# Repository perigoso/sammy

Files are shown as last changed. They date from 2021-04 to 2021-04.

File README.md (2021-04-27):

# sammy

The little brother of [big-sammy](https://github.com/openinput-fw/big-sammy)

[](https://github.com/openinput-fw)

Open source wired mouse hardware.

## Specifications
- 8 kHz sampling rate support
- Zero latency switch debounce
- Onboard configuration memory
- 2 main mouse buttons (satellite* configuration for both)
- 2 side buttons (symmetric to allow easy left/right handedness)
- encoder + wheel button (satellite* configuration)
- RGB Led

`*meaning, a separate board from the core with the controller and sensor`

## Hardware



- ATSAMS70 MCU (ATSAM3UxC)
- Optical sensor [PMW3330, PMW3360, PMW3389, Truemove3]
- onboard conectors:
    - JST PH (2mm pitch) for USB
    - JST SH (1mm pitch) for stellite boards
- M2 mounting hardware

|USB pinout||
|-----|-----|
|1|VCC|
|2|DM|
|3|DP|
|4|GND|
|5|Shield|

## Firmware

sammy is meant to run on [openinput](https://github.com/openinput-fw/openinput).

## License

This hardware is licensed under the [CERN-OHL-P v2](LICENSE) license.

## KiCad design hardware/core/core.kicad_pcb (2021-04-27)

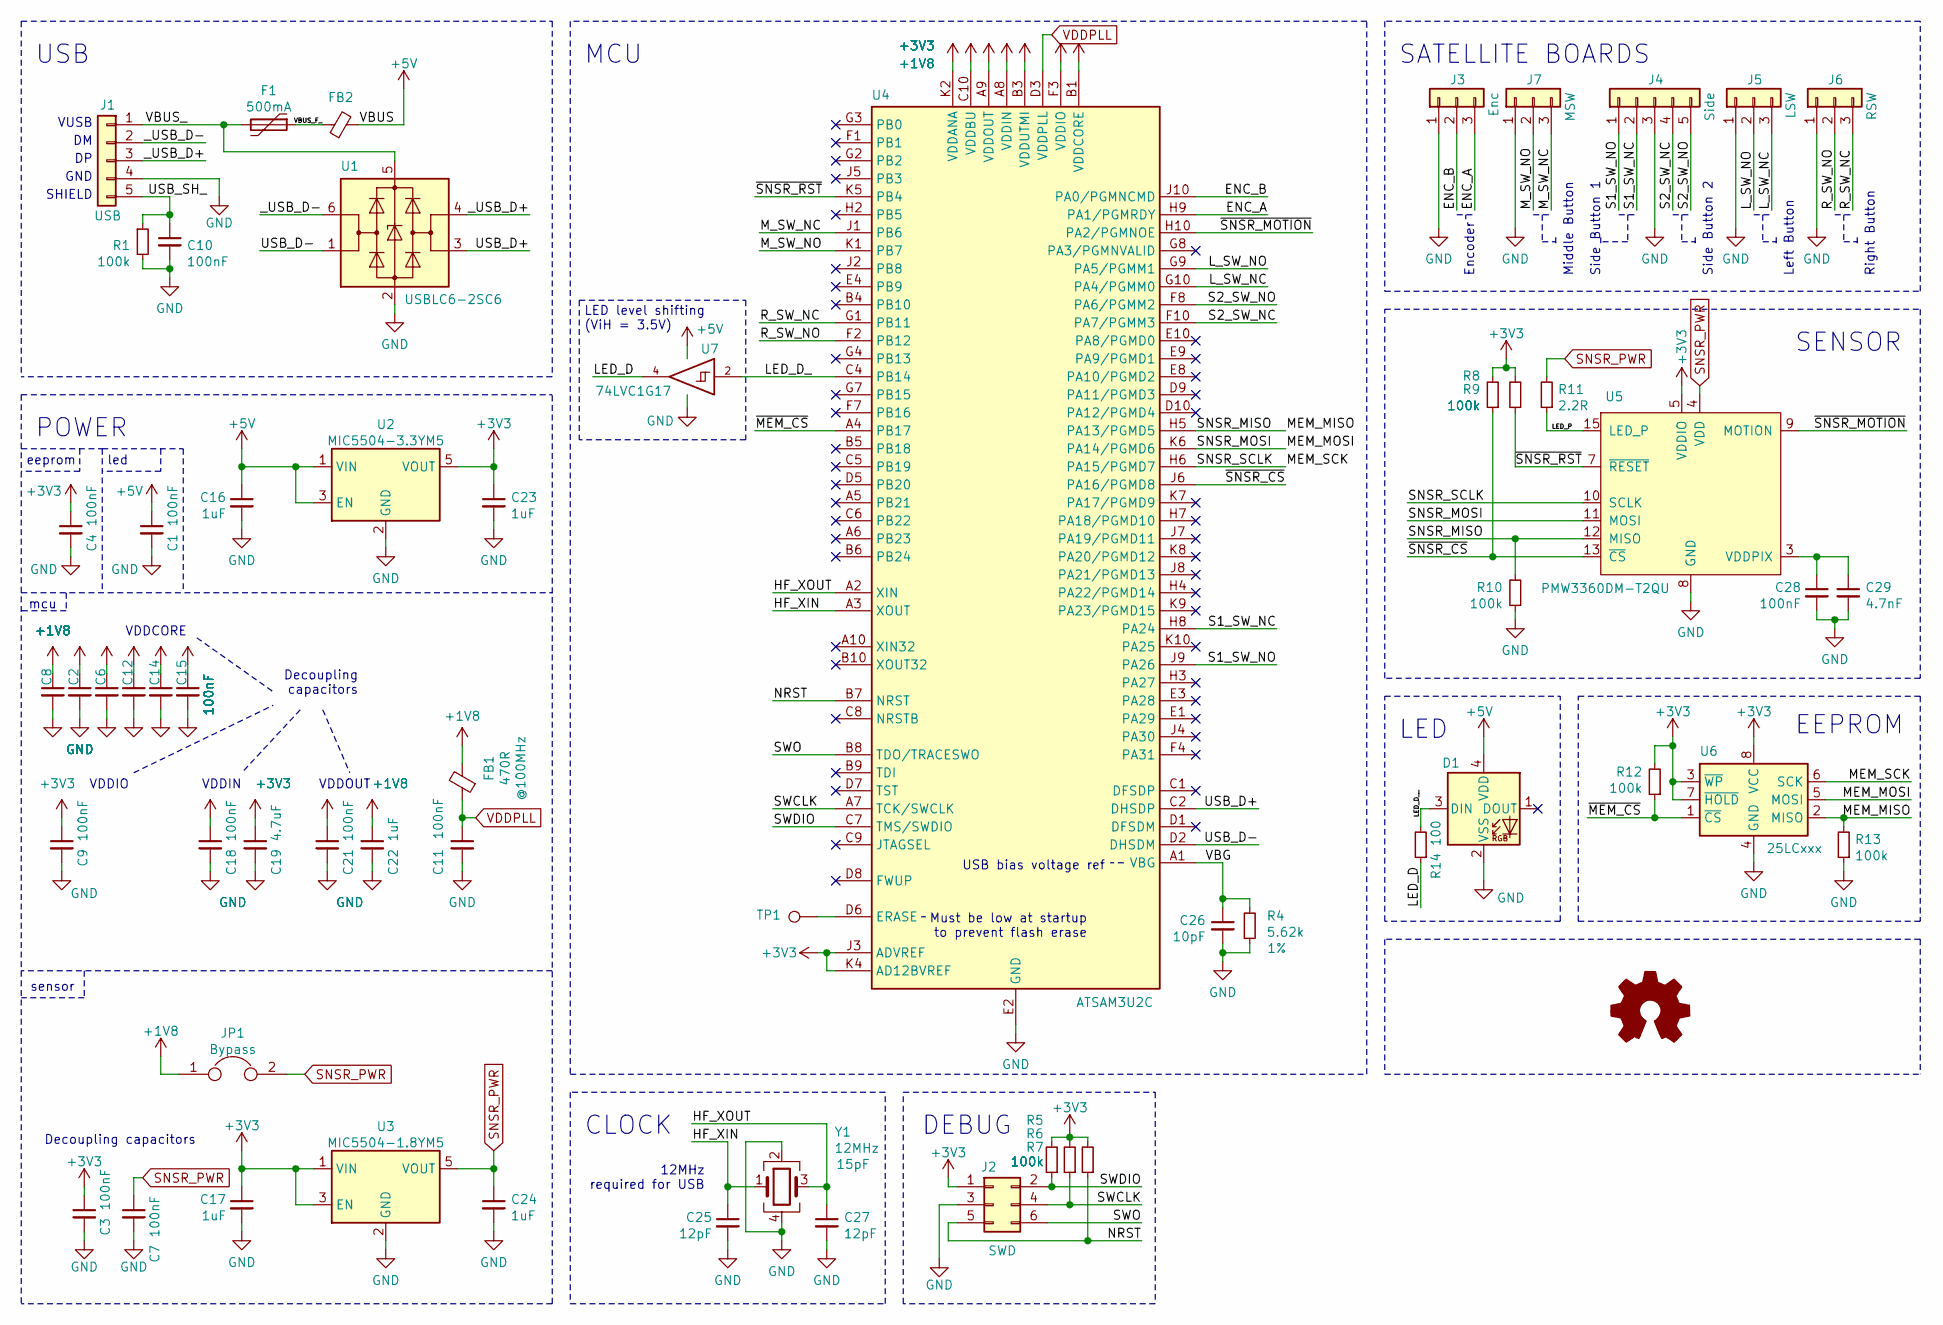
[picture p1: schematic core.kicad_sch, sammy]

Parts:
C1, C2, C3, C4, C6, C7, C8, C9, C10, C11, C12, C14, C15, C18, C21, C28: 100nF; C_0402_1005Metric
C16, C17, C22, C23, C24: 1uF; C_0603_1608Metric
C19: 4.7uF; C_0603_1608Metric
C25, C27: 12pF; C_0402_1005Metric
C26: 10pF; C_0402_1005Metric
C29: 4.7nF; C_0402_1005Metric
D1: ws2812-2020
F1: 500mA; Fuse_0603_1608Metric_Castellated
FB1: 470R; L_0402_1005Metric
FB2: L_0402_1005Metric
J1: USB; JST_PH_B5B-PH-K_1x05_P2.00mm_Vertical
J2: SWD; Tag-Connect_TC2030-IDC-NL_2x03_P1.27mm_Vertical
J3: Enc; JST_SH_BM03B-SRSS-TB_1x03-1MP_P1.00mm_Vertical
J4: Side; JST_SH_BM05B-SRSS-TB_1x05-1MP_P1.00mm_Vertical
J5: LSW; JST_SH_BM03B-SRSS-TB_1x03-1MP_P1.00mm_Vertical
J6: RSW; JST_SH_BM03B-SRSS-TB_1x03-1MP_P1.00mm_Vertical
J7: MSW; JST_SH_BM03B-SRSS-TB_1x03-1MP_P1.00mm_Vertical
JP1: Bypass; SolderJumper-2_P1.3mm_Open_RoundedPad1.0x1.5mm
R1, R5, R6, R7, R8, R9, R10, R12, R13: 100k; R_0402_1005Metric
R4: 5.62k; R_0402_1005Metric; Tolerance 1%
R11: 2.2R; R_0402_1005Metric
R14: 100; R_0402_1005Metric
TP1: TestPoint_Pad_D1.0mm
U1: USBLC6-2SC6; SOT-23-6
U2: MIC5504-3.3YM5; SOT-23-5
U3: MIC5504-1.8YM5; SOT-23-5
U4: ATSAM3U2C; TFBGA-100_9.0x9.0mm_Layout10x10_P0.8mm
U5: PMW3360DM-T2QU; PMW3360
U6: 25LCxxx; DFN-S-8-1EP_6x5mm_P1.27mm
U7: 74LVC1G17; SOT-353_SC-70-5
Y1: 12MHz; Crystal_SMD_3225-4Pin_3.2x2.5mm

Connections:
+1V8: C2.1, C6.1, C8.1, C12.1, C14.1, C15.1, C21.1, C22.1, FB1.2, JP1.1, U4.A9 (VDDOUT), U4.B1 (VDDCORE), U4.D4 (VDDCORE), U4.E7 (VDDCORE), U4.F9 (VDDCORE), U4.G5 (VDDCORE), U4.H1 (VDDCORE)
+3V3: C3.1, C4.1, C9.1, C17.1, C18.1, C19.1, C23.1, J2.1, R5.2, R6.2, R7.2, R8.2, R9.2, R12.2, U2.5 (VOUT), U3.1 (VIN), U3.3 (EN), U4.A8 (VDDIN), U4.B3 (VDDUTMI), U4.C10 (VDDBU), U4.E6 (VDDIO), U4.F3 (VDDIO), U4.F5 (VDDIO), U4.J3 (ADVREF), U4.K2 (VDDANA), U4.K4 (AD12BVREF), U5.5 (VDDIO), U6.3 (~WP), U6.7 (~HOLD), U6.8 (VCC)
+5V: C1.1, C16.1, D1.4 (VDD), FB2.2, U2.1 (VIN), U2.3 (EN), U7.5 (VCC)
/ENC_A: J3.3, U4.H9 (PA1/PGMRDY)
/ENC_B: J3.2, U4.J10 (PA0/PGMNCMD)
/HF_XIN: C25.1, U4.A3 (XOUT), Y1.1
/HF_XOUT: C27.1, U4.A2 (XIN), Y1.3
/LED_D: R14.1, U7.4
/LED_D_: U4.C4 (PB14), U7.2
/LED_D__: D1.3 (DIN), R14.2
/LED_P: R11.1, U5.15 (LED_P)
/L_SW_NC: J5.3, U4.G10 (PA4/PGMM0)
/L_SW_NO: J5.2, U4.G9 (PA5/PGMM1)
/MEM_MOSI: U4.K6 (PA14/PGMD6), U5.11 (MOSI), U6.5 (MOSI)
/MEM_SCK: U4.H6 (PA15/PGMD7), U5.10 (SCLK), U6.6 (SCK)
/M_SW_NC: J7.3, U4.J1 (PB6)
/M_SW_NO: J7.2, U4.K1 (PB7)
/NRST: J2.5, R7.1, U4.B7 (NRST)
/R_SW_NC: J6.3, U4.G1 (PB11)
/R_SW_NO: J6.2, U4.F2 (PB12)
/S1_SW_NC: J4.2, U4.H8 (PA24)
/S1_SW_NO: J4.1, U4.J9 (PA26)
/S2_SW_NC: J4.4, U4.F10 (PA7/PGMM3)
/S2_SW_NO: J4.5, U4.F8 (PA6/PGMM2)
/SNSR_MISO: R10.2, R13.2, U4.H5 (PA13/PGMD5), U5.12 (MISO), U6.2 (MISO)
/SWCLK: J2.4, R6.1, U4.A7 (TCK/SWCLK)
/SWDIO: J2.2, R5.1, U4.C7 (TMS/SWDIO)
/SWO: J2.6, U4.B8 (TDO/TRACESWO)
/USB_D+: U1.3 (I/O2), U4.C2 (DHSDP)
/USB_D-: U1.1 (I/O1), U4.D2 (DHSDM)
/USB_SH_: C10.1, J1.5, R1.1
/VBG: C26.1, R4.2, U4.A1 (VBG)
/VBUS_: F1.2, J1.1, U1.5 (VBUS)
/VBUS_F_: F1.1, FB2.1
/_USB_D+: J1.3, U1.4 (I/O2)
/_USB_D-: J1.2, U1.6 (I/O1)
/~MEM_CS: R12.1, U4.A4 (PB17), U6.1 (~CS)
/~SNSR_CS: R8.1, U4.J6 (PA16/PGMD8), U5.13 (~CS)
/~SNSR_MOTION: U4.H10 (PA2/PGMNOE), U5.9 (MOTION)
/~SNSR_RST: R9.1, U4.K5 (PB4), U5.7 (~RESET)
GND: C1.2, C2.2, C3.2, C4.2, C6.2, C7.2, C8.2, C9.2, C10.2, C11.2, C12.2, C14.2, C15.2, C16.2, C17.2, C18.2, C19.2, C21.2, C22.2, C23.2, C24.2, C25.2, C26.2, C27.2, C28.2, C29.2, D1.2 (VSS), J1.4, J2.3, J3.1, J4.3, J5.1, J6.1, J7.1, R1.2, R4.1, R10.1, R13.1, U1.2 (GND), U2.2 (GND), U3.2 (GND), U4.B2 (GNDUTMI), U4.C3 (GNDPLL), U4.E2 (GND), U4.E5 (GNDBU), U4.F6 (GND), U4.G6 (GND), U4.K3 (GNDANA), U5.8 (GND), U6.4 (GND), U7.3 (GND), Y1.2, Y1.4
unnamed: C28.1, C29.1, U5.3 (VDDPIX)
unnamed: TP1.1, U4.D6 (ERASE)
SNSR_PWR: C7.1, C24.1, JP1.2, R11.2, U3.5 (VOUT), U5.4 (VDD)
VDDPLL: C11.1, FB1.1, U4.D3 (VDDPLL)

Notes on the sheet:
eeprom
USB
POWER
Decoupling capacitors
mcu
sensor
VDDIO
VUSB
GND
SHIELD
led
VDDCORE
VDDIN
VDDOUT
Decoupling capacitors
MCU
LED level shifting (ViH = 3.5V)
CLOCK
12MHz required for USB
DEBUG
Must be low at startup to prevent flash erase
USB bias voltage ref
SATELLITE BOARDS
LED
Encoder
Middle Button
Side Button 1
Side Button 2
Left Button
SENSOR
EEPROM
Right Button

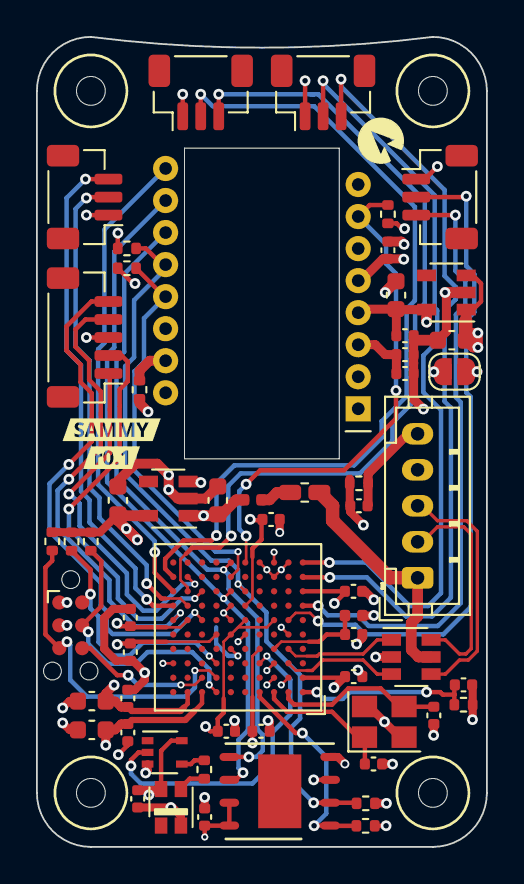
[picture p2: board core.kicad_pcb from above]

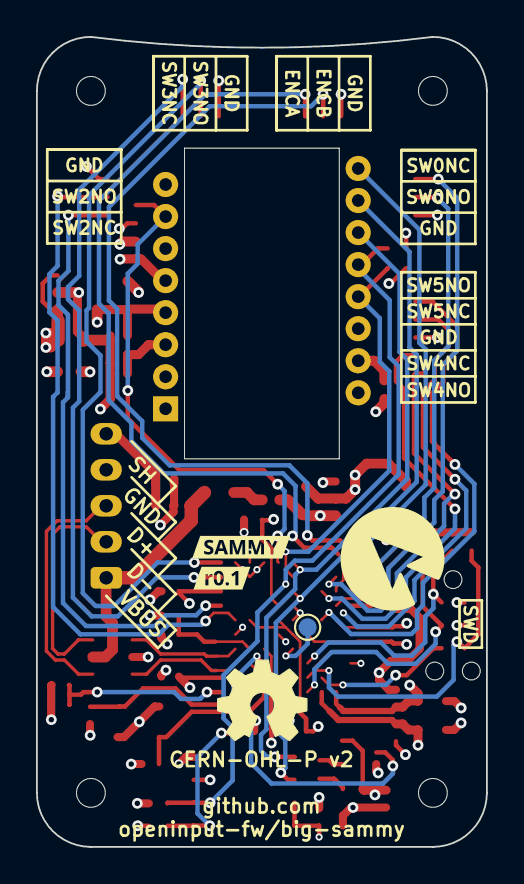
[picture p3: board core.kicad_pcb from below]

Board: 4 copper layers, 25.0 x 45.0 mm, 63 parts (3 on the bottom side), 45 nets.

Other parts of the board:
svg2mod, svg2mod#2, svg2mod#3, svg2mod#4: G***; svg2mod

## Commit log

2021-04-27 kicad: add local libraries (copy from big-sammy + atsam3u)
2021-04-27 pcb: r0.1 schematic and layout based on big-sammy
    [core.kicad_pcb, core.kicad_sch]
2021-04-27 pcb: document label creation

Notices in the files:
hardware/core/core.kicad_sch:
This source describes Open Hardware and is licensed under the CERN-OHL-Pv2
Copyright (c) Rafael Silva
